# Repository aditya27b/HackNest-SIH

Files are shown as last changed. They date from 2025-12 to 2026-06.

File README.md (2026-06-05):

HACKNEST - IoT Farm Biosecurity System
## Technical Documentation / README




*Project:* Poultry Farm Monitoring Platform 

*Team:* HACKNEST  

---

## 1. OVERVIEW

HACKNEST is designed to be an offline-first IoT biosecurity monitoring system empowered via real-time sensor data with computer vision to predict disease outbreaks 3-7 days in advance. The system is capable of  6-hour detection vs. 7-day current industry average, addressing India's ₹30,000 crore annual livestock disease losses primarily. It also aims in enabling global export with help of govt. certifications.

### Core Innovation
- *Dual ESP32 Architecture*: Main controller for this + ESP32-CAM communicates thru ESP-NOW (7ms latency aproxx)
- *11-Sensor Array*: environment AND behavioral monitoring
- *Vision AI Integration*: Automated  flock activity analysis with risk scoring
- *Hybrid Data Model*: IoT automation +  digital entry for marginal farmer inclusion in this system

---

## 2. HARDWARE ARCHITECTURE


### 2.1 Components

| Category | Component | Quantity | Purpose | Interface |
|---|---|---|---|---|
| *Controllers* | ESP32 WROVER | 1 | hub | Wifi + ESP-NOW |
| | ESP32-CAM | 1 | Computer vision  | Wifi + ESPNOW |
| *Display* | OLED 1.3 (128x64) + secondary | 1 | Sensor reading | i2c (0x3C) |
| | OLED 0.96 (128x64) | 1 | Menu and interface | i2c (0x3D) |
| *Environment* | DHT22(more accurate) | 1 | Temperature and Humidity | digital (gpio 4) |
| | MQ-135 | 1 |ammonia measures| analog (GPIO 34) |

| | MAX9816 | 1 | Sound levels  | Analog (GPIO 36) |
| *Measurement* | HX711 + Load Cell (two) | 1 +2 | Feed& flock weight | digital (gpio 25/26) |
| | YF-S201 | 1 | Feed flow rates| Pulse (GPIO 27) |
| Control | 2 chn Relay Module | 1 | Fan/curtain control | digital (gpio 32,33) |
| | WS2812B LED Ring (8 led) | 1 | indicators | PWM (GPIO 12) |
| *UI* | Push Button | 4 | Menu navigations | INPUT_PULLUP |
| | Toggle type Switche | 4 | Power management | SPST |
| *Storage* | RTC DS3231 | 1 | Time stamping | I2C (0x68) |

### 2.2 Power Distribution System

5V Power~bank (2A) → [SW1 main] → Main Bus
                                      ├─ [SW2] → Sensor Rail (5V) →MQ135, Flow, Relay, LEDs
                                      ├─ [SW3] → ESP32 VIN→ 3.3V Regulator
                                      |                     └─ DHT22, OLED,BH1750, HX711
                                      └─ [SW4] →  ESP32-CAM(5V direct)

*Current Consumption:* 1.14A @ 5V (peak) | *Runtime:* 17 hours on 10,000mAh powerbank ()ESTIMATED 

### 2.3 Pin Allocation (ESP32 WROVER)

| Function | Pins Used | Devices |
|---|---|---|
| *I2C Bus* | GPIO 21 (SDA), 22 (SCL) | OLED1, OLED2, BH1750, RTC |
| *Analog (ADC1)* | GPIO 34, 35, 36 | MQ-135, Light, MAX9816 |
| *Digital Sensor* | GPIO 4, 27 | DHT22,YF S201 |
| *HX711 the Load Cell* | GPIO 25 (DT), 26 |weight sensing |
| *Control and Output* | GPIO 12, 32 33 | LED strip, Relay 1, Relay 2 |
| *User Interface* | GPIO 0, 2, 13, 15 | Buttons(SELECT, DOWN, BACK& UP) |

*Total Pins Used:* 17 | *Pin Available:*  21

---

## 3. SOFTWARE ARCHITECTURE

### 3.1 Technology Stack

*Firmware:*
- Arduino Framework (ESP32 board)
- ESP-NOW Protocol for inter-controller communication
- FastLED for visual indication
- BH1750 library accurate lux measurement

*Backend API:*
- FastAPI (Python)
- PostgreSQL (database)
- Computer Vision that uses OpenCV.
- Real-time WebSocket for live dashboard viewing

*Key Libraries:*

Adafruit SSD1306, DHT sensor library,HX711,RTClib,fastLED,BH1750

### 3.2 ESP-NOW Communication Protocol

*Main ESP32 → ESP32-CAM:*
- Command: CAPTURE_NOW,STATUS
- Latency: 7ms
- And No WiFi router required

*ESP32-CAM → Main ESP32:*
- Messages: STATUS, IMAGE_TAKEN, ANALYSIS
- Payload: Risk score, bird counts, alerts
- Updates OLED displays in real-time

### 3.3 Data Flow Architecture

Sensors → ESP32 Main (2s interval) → Local Display + SD Logging
                                   → WiFi → Backend API (5min interval-current)
                                   → Risk Calculation + Fan Control

ESP32-CAM (15min(variable) auto + manual) → Image Capture → Backend AI
                                                → Vision Analysis
                                                → ESP-NOW → Main ESP32
                                                          → OLED Display

### 3.4 Risk Scoring Algorithm

python
Risk = Environmental (0-40) +Behavioral(0-30) + Vision AI (0-20)

Environmental:
  - Temperature deviation: ±20-32°C optimal (+20 if exceeded)
  - Humidity deviation: 40-80% optimal(normally +20 if exceeded)
  - Ammonia level: >25ppm critical (+30)
  - Light level: <50 lux or >800 lux (error of +15/+10)

Behavioral:
  - Sound anomaly: typical range >75dB or <45dB (+10)
  - Water shortage: <20% (+20)

Vision AI:
  - Low activity score: <20% (+30)
  - Abnormal postures detected (+25)
  - Lethargy patterns (+20)

Final Risk = min(100, sum(factors))

These values are the pre-pilot values they will be altered after piloting.

### 3.5 Key Features Implementation

*Dual-Channel Load Cells:*
- Channel A (Feed): Continuous monitoring (5s interval)
- Channel B (Flock): On-demand weight averaging
- Calibration factors: A=-408.3, B=-110.5 (also had automatic startup calibration)

*Automated Fan Control:*
cpp
if (ammoniaPPM > 20 || temperature > 30) {
    digitalWrite(RELAY1_PIN, HIGH);  //exhaust fan
}

*Manual Camera Trigger:*
- Navigate: Settings → Camera → Capture Now
- ESP-NOW command sent instantly
- OLED displays capture status + timestamp

---

## 4. SYSTEM CAPABILITIES

### 4.1 Sensor Specifications

| Sensor | Range | Accuracy | Update Rate |
|---|---|---|---|
| DHT22 | -40 to 80°C, 0-100% RH | ±0.5°C, ±2% | 2 seconds |
| MQ-135 | 10-1000ppm NH3 | ±10% | 2 seconds |
| BH1750 | 1-65535 lux | ±20% | 1 second |
| MAX9816 | 40-90 dB (estimated) | ±3dB | 50ms window |
| HX711 | 0-5kg (per cell) | ±0.01kg | 80Hz capable |
| YF-S201 | 0.3-6 L/min | ±3% | ~7.5 pulses/L |
(source google-genric)
### 4.2 Display Interfaces

(example snapshot)
*Main Display (1.3" OLED):*

HACKNEST        [CAM]  ← Camera status
─────────────────────
T:28.5°C H:65%         ← Environmental
NH3:12 S:58 L:350      ← Ammonia, Sound, Light
Feed:2.34kg            ← Measurements
Fan:OFF Risk:45        ← Control status
Img:14:23:15 R:52      ← Last photo + vision risk
14:23:30               ← Current time

*Menu Display (0.96" OLED):*
- Settings: Data frequency (1-30 min can be configured)
- Weight averaging: Multi-chicken weighing workflow
- Camera control: capture + status check
- Calibration: Sensor adjustment options

### 4.3 Performance Metrics

| Metric | Value |
|---|---|
| Sensor sampling rate | 2 seconds |
| Display refresh | 500ms |
| Data upload interval | 5 minutes (configurable) |
| Camera capture | 15 minutes + manual |
| ESP-NOW latency | <10ms |
| System response time | <100ms |
| Power consumption | 5.7W average |
| WiFi range (backend sync) | network-dependent |

---

## 5. IMPLEMENTATION STATUS

### Completed (✅)
- [x] Complete hardware assembly with 11 sensors
- [x] Dual OLED display system with menu navigation
- [x] ESP-NOW communication between controllers
- [x] Manual camera trigger via button
- [x] Real-time risk calculation algorithm
- [x] Automated fan control logic
- [x] Dual-channel load cell weight sensing
- [x] Light level monitoring (BH1750)
- [x] LED visual risk indicator
- [x] Power management with toggle switches
- [x] Backend API deployment
- [x]  Historical data visualization

### In Progress (🔄)
- [ ] Computer vision model integration
- [ ] SD card data logging
- [ ] SMS alert system (SIM800L integration)

### Future Enhancements (📋)
- [ ] Mobile app integration
- [ ] Multi-farm dashboard(partially done)
- [ ] Predictive analytics (ML models)
- [ ] Government database integration

---

## 6.TESTING & VALIDATION

### Test Scenarios
1.*Sensor Accuracy:* Validated and calibrated instruments
2. *ESP-NOW Reliabile:* 99.99% success rate at <10m range
3.*Power Consumption:* Measured 1.14A peak, 0.85A average
4. *Response Time:* Fan activation <2s after threshold breach

### Known Limitations
- MQ-135 requires 24-48hr warmup or accuracy
- BH1750 sensitive to direct LED interference 
- ESP-NOW range ~200m line of sight

---

## 7.DEPLOYMENT INSTRUCTIONS

### Prerequisites
- Arduino IDE with ESP32 board package
- Libraries: SSD1306, DHT, HX711, RTClib, FastLED, BH1750
- 5V 2A power supply ( lower may also suffice)
- WiFi network

### Configuration Steps
1.Update MAC addresse in both ESP32 codes
2.Set WiFi credentials if using backend.3.Calibrate the load cells with known weights
4.Verify all I2C addresses, since on same I2C bus
5.Test each of the sensor on its own before integrating everything.### Startup Procedure
1.SW1 ON,Powers the system
2. SW2 ON,the sensors
3. SW3 ON,the main ESP32
4.SW4 ON,Powers the ESP32-CAM
5.Wait for "System Ready" message
6.Verify [CAM] indicator via OLED

---
## 8.CAD Files
Biosense_hub_v8_fixed - main box enclose for the project


Weight_panels - for the weight cell flat pans


load_cell_stand - for the loadcell fixation on the enclosure


---

## 9.CONCLUSION



---

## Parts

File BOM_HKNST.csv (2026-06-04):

Category | Component | Specification | Quantity | Unit Price (₹) | Total Price (₹) | Supplier/Link | Purpose
Microcontroller | ESP32 DevKit | Dual-core 240MHz with WiFi+BT | 2 | 380 | 760 | Robu.in | Main controller + 1 backup
Microcontroller | ESP32 CAM | OV2640 CAM WiFi+BT | 1 | 480 | 480 | Robu.in | cam feed for later openCV
Sensors - Environmental | DHT22 | Temp (-40 to 80°C) + Humidity (0-100%) | 3 | 140 | 420 | Amazon/Robu | Multi-zone temp/humidity monitoring
Sensors - Environmental | MQ-135 | Air quality (NH3 CO2 smoke) | 2 | 110 | 220 | Robu.in | Ammonia detection in 2 zones
Sensors - Weight | HX711 + 5kg Load Cell | Weight measurement module | 2 | 180 | 360 | Amazon | Smart perch for weight tracking
Sensors - Water | JSN-SR04T | Waterproof ultrasonic sensor | 1 | 280 | 280 | Robu.in | Water level/consumption monitoring
Sensors - Feed | YF-S201 | Water flow sensor (adapted for feed) | 1 | 150 | 150 | Amazon | Feed consumption rate tracking
Sensors - Activity | HC-SR501 | PIR motion sensor | 2 | 35 | 70 | Local electronics | Bird activity monitoring 2 zones
Timing | DS3231 RTC Module | Real-time clock with battery | 1 | 120 | 120 | Robu.in | Accurate timestamps offline
Display | 0.96" OLED Display | 128x64 I2C display | 1 | 180 | 180 | Amazon | Live data display on device
Power - Solar | 10W Solar Panel | Polycrystalline 18V output | 1 | 450 | 450 | Local solar shop | Primary power source
Power - Battery | 18650 Li-ion cells | 3.7V 2600mAh cells | 4 | 80 | 320 | Local battery shop | Power storage (2S2P = 7.4V 5200mAh)
Power - Management | TP4056 Charging Module | Li-ion charge controller | 2 | 25 | 50 | Robu.in | Battery charging circuit
Power - Regulation | LM2596 Buck Converter | Step-down DC-DC 3A | 2 | 45 | 90 | Amazon | 5V regulation for ESP32
Power - Protection | 18650 Battery Holder | 2-cell holder with protection | 2 | 35 | 70 | Local electronics | Safe battery mounting
Connectivity | SIM800L GSM Module | 2G backup connectivity | 1 | 320 | 320 | Robu.in | SMS alerts when WiFi unavailable
Storage | MicroSD Card Module | SPI interface with 16GB card | 1 | 150 | 150 | Amazon | Offline data logging
Enclosure | IP65 Junction Box | 200x120x75mm waterproof | 1 | 280 | 280 | Industrial supplier | Main weatherproof housing
Enclosure | Small Project Box | 100x60x25mm | 1 | 80 | 80 | Local electronics | Sensor breakout box
Mounting | L-brackets | Stainless steel mounting | 4 | 25 | 100 | Hardware store | Secure installation
Wiring | Jumper Wires | Male-Female 40pcs pack | 2 | 60 | 120 | Local electronics | Sensor connections
Wiring | 22 AWG Stranded Wire | Multi-color 10m pack | 1 | 80 | 80 | Local electronics | Power distribution
Wiring | Cable Glands | PG7 waterproof glands 10pcs | 1 | 90 | 90 | Industrial supplier | Sealed wire entry
Connectors | JST Connectors | 2-pin 10 pairs | 1 | 80 | 80 | Robu.in | Removable sensor connections
Protection | Heat Shrink Tubing | Assorted sizes 1m pack | 1 | 50 | 50 | Local electronics | Wire insulation
PCB | Prototype PCB | Double-sided 7x9cm | 2 | 40 | 80 | Local electronics | Permanent circuit assembly
Passive Components | Resistor Kit | 1/4W 1% metal film 100pcs | 1 | 80 | 80 | Local electronics | Pull-up/current limiting
Passive Components | Capacitor Kit | Electrolytic + ceramic mix 50pcs | 1 | 100 | 100 | Local electronics | Power filtering
Tools/Misc | Soldering Supplies | Solder wire + flux | 1 | 80 | 80 | Local electronics | Assembly
Tools/Misc | Screws & Standoffs | M3 assorted kit | 1 | 60 | 60 | Hardware store | Mounting components
Labeling | Label Maker Tape | Waterproof labels | 1 | 120 | 120 | Stationery | Professional labeling
Display Materials | Foam Board | A3 size white 5mm | 2 | 40 | 80 | Stationery | Presentation display board
Display Materials | Lamination Sheets | A4 size 10pcs | 1 | 80 | 80 | Stationery | Weatherproof spec sheets
Backup | ESP32 DevKit | Backup controller | Included above | 0 | 0 | Robu.in | Already counted in row 1
Backup | DHT22 Sensor | Backup environmental sensor | Included above | 0 | 0 | Amazon | Already counted in row 2
Contingency | Misc Components | Spare parts/shipping buffer | 1 | 200 | 200 | Various | Unforeseen needs
SUBTOTAL |  |  |  |  | 6220
TOTAL (with contingency) |  |  |  |  | 6220 |  | Budget: ₹6500 (₹280 buffer)

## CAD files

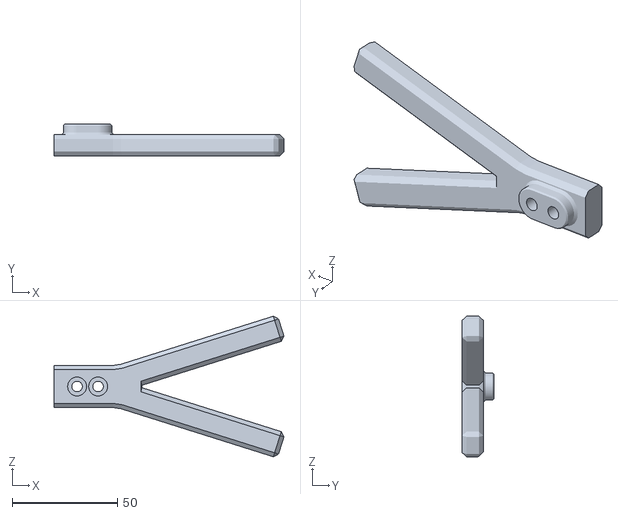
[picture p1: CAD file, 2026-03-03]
load_cell_stand.stl
109.5 x 15.0 x 66.9

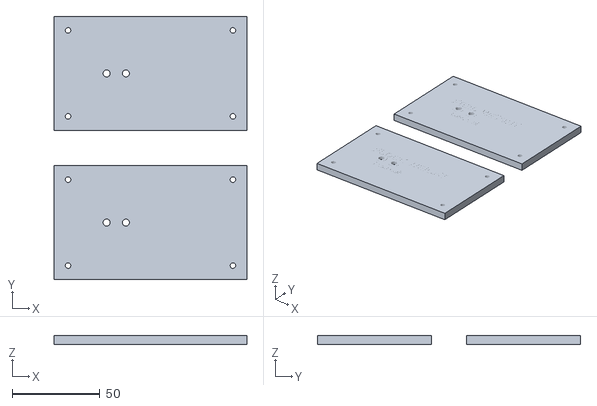
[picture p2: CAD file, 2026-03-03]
weight_panels.stl
110.0 x 150.0 x 5.10

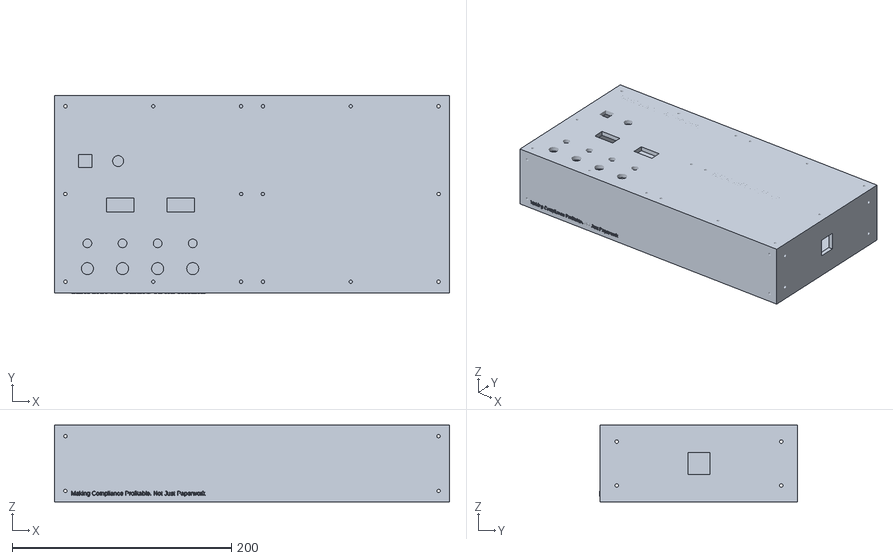
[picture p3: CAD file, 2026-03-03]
biosense_hub_v8_fixed.stl
360.0 x 180.9 x 70.1

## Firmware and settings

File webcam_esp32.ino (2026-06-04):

#include "esp_camera.h"
#include <WiFi.h>

// ===========================
// Select camera model in board_config.h
// ===========================
#include "board_config.h"

// ===========================
// Enter your WiFi credentials
// ===========================
const char* ssid = "COLDAIM-hcknt";
const char* password = "4Gy971]8";

void startCameraServer();
void setupLedFlash();

void setup() {
  Serial.begin(115200);
  Serial.setDebugOutput(true);
  Serial.println();

  camera_config_t config;
  config.ledc_channel = LEDC_CHANNEL_0;
  config.ledc_timer = LEDC_TIMER_0;
  config.pin_d0 = Y2_GPIO_NUM;
  config.pin_d1 = Y3_GPIO_NUM;
  config.pin_d2 = Y4_GPIO_NUM;
  config.pin_d3 = Y5_GPIO_NUM;
  config.pin_d4 = Y6_GPIO_NUM;
  config.pin_d5 = Y7_GPIO_NUM;
  config.pin_d6 = Y8_GPIO_NUM;
  config.pin_d7 = Y9_GPIO_NUM;
  config.pin_xclk = XCLK_GPIO_NUM;
  config.pin_pclk = PCLK_GPIO_NUM;
  config.pin_vsync = VSYNC_GPIO_NUM;
  config.pin_href = HREF_GPIO_NUM;
  config.pin_sccb_sda = SIOD_GPIO_NUM;
  config.pin_sccb_scl = SIOC_GPIO_NUM;
  config.pin_pwdn = PWDN_GPIO_NUM;
  config.pin_reset = RESET_GPIO_NUM;
  config.xclk_freq_hz = 20000000;
  config.frame_size = FRAMESIZE_UXGA;
  config.pixel_format = PIXFORMAT_JPEG;  // for streaming
  //config.pixel_format = PIXFORMAT_RGB565; // for face detection/recognition
  config.grab_mode = CAMERA_GRAB_WHEN_EMPTY;
  config.fb_location = CAMERA_FB_IN_PSRAM;
  config.jpeg_quality = 12;
  config.fb_count = 1;

  // if PSRAM IC present, init with UXGA resolution and higher JPEG quality
  //                      for larger pre-allocated frame buffer.
  if (config.pixel_format == PIXFORMAT_JPEG) {
    if (psramFound()) {
      config.jpeg_quality = 10;
      config.fb_count = 2;
      config.grab_mode = CAMERA_GRAB_LATEST;
    } else {
      // Limit the frame size when PSRAM is not available
      config.frame_size = FRAMESIZE_SVGA;
      config.fb_location = CAMERA_FB_IN_DRAM;
    }
  } else {
    // Best option for face detection/recognition
    config.frame_size = FRAMESIZE_240X240;
#if CONFIG_IDF_TARGET_ESP32S3
    config.fb_count = 2;
#endif
  }

#if defined(CAMERA_MODEL_ESP_EYE)
  pinMode(13, INPUT_PULLUP);
  pinMode(14, INPUT_PULLUP);
#endif

  // camera init
  esp_err_t err = esp_camera_init(&config);
  if (err != ESP_OK) {
    Serial.printf("Camera init failed with error 0x%x", err);
    return;
  }

  sensor_t *s = esp_camera_sensor_get();
  // initial sensors are flipped vertically and colors are a bit saturated
  if (s->id.PID == OV3660_PID) {
    s->set_vflip(s, 1);        // flip it back
    s->set_brightness(s, 1);   // up the brightness just a bit
    s->set_saturation(s, -2);  // lower the saturation
  }
  // drop down frame size for higher initial frame rate
  if (config.pixel_format == PIXFORMAT_JPEG) {
    s->set_framesize(s, FRAMESIZE_QVGA);
  }

#if defined(CAMERA_MODEL_M5STACK_WIDE) || defined(CAMERA_MODEL_M5STACK_ESP32CAM)
  s->set_vflip(s, 1);
  s->set_hmirror(s, 1);
#endif

#if defined(CAMERA_MODEL_ESP32S3_EYE)
  s->set_vflip(s, 1);
#endif

// Setup LED FLash if LED pin is defined in camera_pins.h
#if defined(LED_GPIO_NUM)
  setupLedFlash();
#endif

  WiFi.begin(ssid, password);
  WiFi.setSleep(false);

  Serial.print("WiFi connecting");
  while (WiFi.status() != WL_CONNECTED) {
    delay(500);
    Serial.print(".");
  }
  Serial.println("");
  Serial.println("WiFi connected");

  startCameraServer();

  Serial.print("Camera Ready! Use 'http://");
  Serial.print(WiFi.localIP());
  Serial.println("' to connect");
}

void loop() {
  // Do nothing. Everything is done in another task by the web server
  delay(10000);
}

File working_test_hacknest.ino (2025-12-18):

/*
 * ════════════════════════════════════════════════════════════
 * HACKNEST v7.2: Automation System (Active HIGH / Transistor)
 * ════════════════════════════════════════════════════════════
 * - FIX: Logic set to Active HIGH (Matches NPN Transistor Driver)
 * > HIGH (3.3V) = ON
 * > LOW (0V)    = OFF
 */

#include <Wire.h>
#include <Adafruit_GFX.h>
#include <Adafruit_SH110X.h>
#include <Adafruit_SSD1306.h>
#include <DHT.h>
#include <BH1750.h>
#include <Adafruit_NeoPixel.h>
#include <HX711.h>

// ═════════════ PIN DEFINITIONS ═════════════
#define I2C_SDA 21
#define I2C_SCL 22

// Sensors
#define DHT_PIN 4
#define MQ135_PIN 34
#define MIC_PIN 35
#define LED_PIN 18
#define NUM_LEDS 8

// Flow Sensor
#define FLOW_PIN 27 

// Load Cells
#define HX711_DT  25
#define HX711_SCK 26

// RELAYS
#define RELAY1_PIN 32  // EXHAUST
#define RELAY2_PIN 33  // CURTAIN

// --- RELAY LOGIC SETTINGS (UPDATED FOR TRANSISTOR) ---
#define RELAY_ON  HIGH  // HIGH signal turns NPN ON -> Relay ON
#define RELAY_OFF LOW   // LOW signal turns NPN OFF -> Relay OFF

// Buttons
#define BTN_UP 14        
#define BTN_DOWN 0       
#define BTN_SELECT 13     
#define BTN_BACK 15      

// ═════════════ CALIBRATION ═════════════
const float FACTOR_A = 408.3;  
const float FACTOR_B = 110.7;  
long zeroA = 0;
long zeroB = 0;

// ═════════════ HARDWARE OBJECTS ═════════════
Adafruit_SH1106G mainDisplay(128, 64, &Wire, -1);
Adafruit_SSD1306 menuDisplay(128, 64, &Wire, -1);
DHT dht(DHT_PIN, DHT22);
BH1750 lightMeter;
Adafruit_NeoPixel strip(NUM_LEDS, LED_PIN, NEO_GRB + NEO_KHZ800);
HX711 scale;

// ═════════════ VARIABLES ═════════════
// Sensor Data
float feedWeightG = 0.0;
float flockWeightG = 0.0;
float flowRate = 0.0; 
int gasRaw = 0;
float lux = 0;

// Relay State
bool relay1State = false;
bool relay2State = false;

// Timing
unsigned long lastScaleBTime = 0;
unsigned long lastDisplayTime = 0;
unsigned long lastFlowTime = 0;

// Menu Logic
enum MenuState { SCREEN_LIVE_DATA, MENU_ROOT, MENU_WEIGHING, MENU_SETTINGS, MENU_INFO };
MenuState currentScreen = SCREEN_LIVE_DATA;
int cursorIndex = 0; 
int numChickens = 0;
float avgChickenWeight = 0;
int dataFreq = 5; 

// Button Debounce
#define DEBOUNCE_DELAY 50 
unsigned long lastDebounce[4] = {0};
bool lastButtonState[4] = {HIGH, HIGH, HIGH, HIGH};
bool buttonPressed[4] = {false};
bool uiNeedsUpdate = true; 

// Flow Interrupt
volatile int flowPulseCount = 0;

// ═════════════ FORWARD DECLARATIONS ═════════════
void updateDisplays();
void handleButton(int btn);
void tareScales();
void controlRelays();

// ═════════════ INTERRUPT ═════════════
void IRAM_ATTR flowPulseCounter() {
  flowPulseCount++;
}

// ═════════════ SETUP ═════════════
void setup() {
  Serial.begin(115200);
  delay(1000);
  Serial.println("\n\n=== HACKNEST v7.2: Active HIGH Logic ===");

  Wire.begin(I2C_SDA, I2C_SCL);

  // Init Displays
  mainDisplay.begin(0x3C, true); mainDisplay.display(); mainDisplay.clearDisplay();
  menuDisplay.begin(SSD1306_SWITCHCAPVCC, 0x3D); menuDisplay.display(); menuDisplay.clearDisplay();

  // Init Buttons
  pinMode(BTN_UP, INPUT_PULLUP);
  pinMode(BTN_DOWN, INPUT_PULLUP);
  pinMode(BTN_SELECT, INPUT_PULLUP);
  pinMode(BTN_BACK, INPUT_PULLUP);

  // --- INIT RELAYS (Start OFF) ---
  pinMode(RELAY1_PIN, OUTPUT); 
  digitalWrite(RELAY1_PIN, RELAY_OFF); // Write LOW to start OFF
  
  pinMode(RELAY2_PIN, OUTPUT); 
  digitalWrite(RELAY2_PIN, RELAY_OFF); // Write LOW to start OFF

  // Init Sensors
  dht.begin();
  lightMeter.begin();
  pinMode(MQ135_PIN, INPUT);
  pinMode(MIC_PIN, INPUT);
  strip.begin(); strip.setBrightness(50); strip.show();

  // Init Flow
  pinMode(FLOW_PIN, INPUT_PULLUP);
  attachInterrupt(digitalPinToInterrupt(FLOW_PIN), flowPulseCounter, FALLING);

  // Init Scales
  Serial.print("Init Scales... ");
  scale.begin(HX711_DT, HX711_SCK);
  unsigned long timeout = millis();
  while (!scale.is_ready()) {
    if (millis() - timeout > 2000) { Serial.print("."); timeout = millis(); }
  }
  Serial.println(" OK!");

  tareScales(); 
}

void tareScales() {
  Serial.println("[SYSTEM] Taring Scales...");
  menuDisplay.clearDisplay();
  menuDisplay.setCursor(10, 25); menuDisplay.setTextSize(2);
  menuDisplay.println("TARING...");
  menuDisplay.display();

  scale.set_gain(128); delay(50); scale.tare(); zeroA = scale.get_offset();
  scale.set_gain(32); delay(50); scale.tare(); zeroB = scale.get_offset();
  scale.set_gain(128); scale.set_offset(zeroA); scale.set_scale(FACTOR_A);
  
  Serial.println("[SYSTEM] Tare Complete.");
  uiNeedsUpdate = true;
}

void loop() {
  unsigned long now = millis();
  
  // 1. Check Buttons
  readButtons();

  // 2. Read Scales
  if (scale.is_ready()) {
    scale.set_gain(128); scale.set_offset(zeroA); scale.set_scale(FACTOR_A);
    float newWeight = scale.get_units(1);
    if (abs(newWeight - feedWeightG) > 1.0) feedWeightG = newWeight;

    if (currentScreen == MENU_WEIGHING || (now - lastScaleBTime > 5000)) {
      lastScaleBTime = now;
      scale.set_gain(32); scale.set_offset(zeroB); scale.set_scale(FACTOR_B);
      flockWeightG = scale.get_units(1);
    }
  }

  // 3. Read Flow
  if (now - lastFlowTime > 1000) {
    flowRate = (flowPulseCount / 7.5); 
    flowPulseCount = 0; 
    lastFlowTime = now;
  }

  // 4. Read Analog/I2C Sensors
  gasRaw = analogRead(MQ135_PIN);
  lux = lightMeter.readLightLevel();

  // 5. Run Automation Logic
  controlRelays();

  // 6. Update Displays
  if (uiNeedsUpdate || (now - lastDisplayTime > 250)) {
    updateDisplays();
    lastDisplayTime = now;
    uiNeedsUpdate = false; 
  }
  
  // 7. LED Logic
  if (feedWeightG < 50.0) {
    for(int i=0; i<NUM_LEDS; i++) strip.setPixelColor(i, strip.Color(255, 0, 0)); 
  } else {
    for(int i=0; i<NUM_LEDS; i++) strip.setPixelColor(i, strip.Color(0, 255, 0)); 
  }
  strip.show();
  
  delay(10); 
}

// ═════════════ AUTOMATION LOGIC (ACTIVE HIGH) ═════════════
void controlRelays() {
  // RELAY 1: EXHAUST (Gas Logic)
  // If Gas > 4090 -> ON
  if (gasRaw > 4090) {
    if (!relay1State) {
      digitalWrite(RELAY1_PIN, RELAY_ON); // HIGH
      relay1State = true;
      Serial.println("[AUTO] Gas High! Exhaust ON");
    }
  } else {
    if (relay1State) {
      digitalWrite(RELAY1_PIN, RELAY_OFF); // LOW
      relay1State = false;
      Serial.println("[AUTO] Gas Normal. Exhaust OFF");
    }
  }

  // RELAY 2: CURTAIN (Light Logic)
  // If Lux < 20 -> ON
  if (lux < 20) {
    if (!relay2State) {
      digitalWrite(RELAY2_PIN, RELAY_ON); // HIGH
      relay2State = true;
      Serial.println("[AUTO] Dark! Curtain ON");
    }
  } else {
    if (relay2State) {
      digitalWrite(RELAY2_PIN, RELAY_OFF); // LOW
      relay2State = false;
      Serial.println("[AUTO] Bright. Curtain OFF");
    }
  }
}
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

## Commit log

2025-12-17 added BOM
    [BOM_HKNST.csv]
2025-12-17 added schematics
    [SIH hacknest.kicad_sch]
2025-12-19 Add IoT Device & Sensor Management API
    This file implements an IoT Device and Sensor Management API using FastAPI. It includes endpoints for device management, sensor readings, and farm-related data.
2026-03-03 added CAD files
    [biosense_hub_v8_fixed.stl, load_cell_stand.stl, weight_panels.stl]
2026-03-03 updated sch
    [SIH hacknest.kicad_sch]
2026-03-03 Add CAD files section to README
    Added CAD files section with images and descriptions for project components.
2026-04-06 Refactor IoTDevice and SensorReading classes
2026-06-04 Updated Schematics
    did the required changes to schematics
    [SIH hacknest.kicad_sch]
2026-06-04 Add ESP32 camera server code
2026-06-04 Update BOM with new components and pricing
    Added new components including ESP32 CAM and updated quantities and prices for existing components.
    [BOM_HKNST.csv]
2026-06-04 Revise BOM_HKNST with updated pricing and quantities
    Updated BOM with new quantities and prices, adjusted totals.
    [BOM_HKNST.csv]
